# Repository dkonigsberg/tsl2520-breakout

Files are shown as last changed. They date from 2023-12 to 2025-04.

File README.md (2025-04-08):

# TSL2520 Breakout Board

This repository contains the [KiCad](http://kicad.org/) project
with the complete circuit schematics and PCB layout for a breakout
board that supports a certain series of 1.8V light sensors from
[AMS](https://ams-osram.com/).

The supported selection of sensors all appear to be pin-compatible,
interface compatible, and only differ in minor ways. These sensors
include:

* [TSL2520](https://ams-osram.com/en/tsl2520) - Light sensor with Clear and IR channels
* [TSL2521](https://ams-osram.com/en/tsl2521) - Light sensor with Clear and IR channels, and flicker detection
* [TSL2522](https://ams-osram.com/en/tsl2522) - Light sensor with Photopic and IR channels, and flicker detection
* [TCS3410](https://ams-osram.com/en/tcs3410) - Light sensor with Color channels and flicker detection

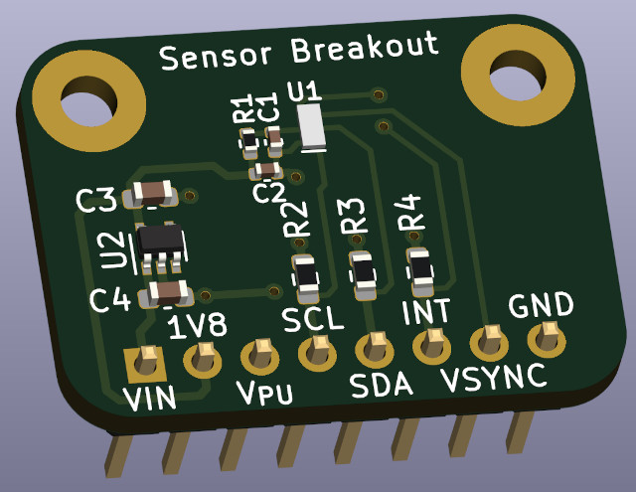
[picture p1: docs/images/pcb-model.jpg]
Board


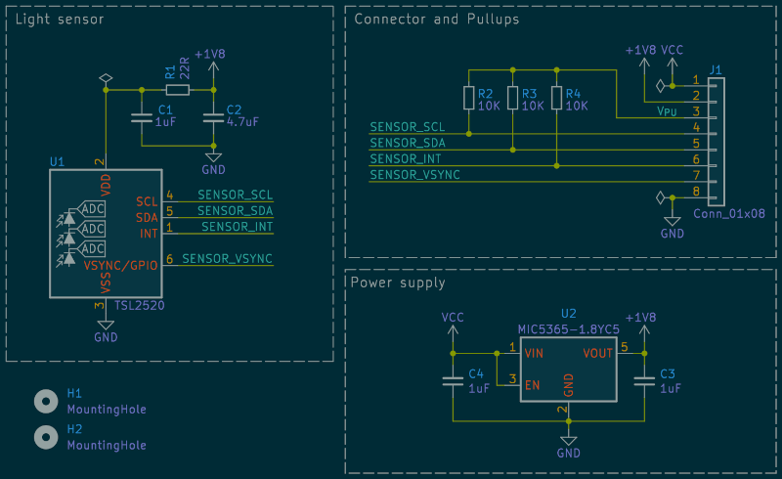
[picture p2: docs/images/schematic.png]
Schematic


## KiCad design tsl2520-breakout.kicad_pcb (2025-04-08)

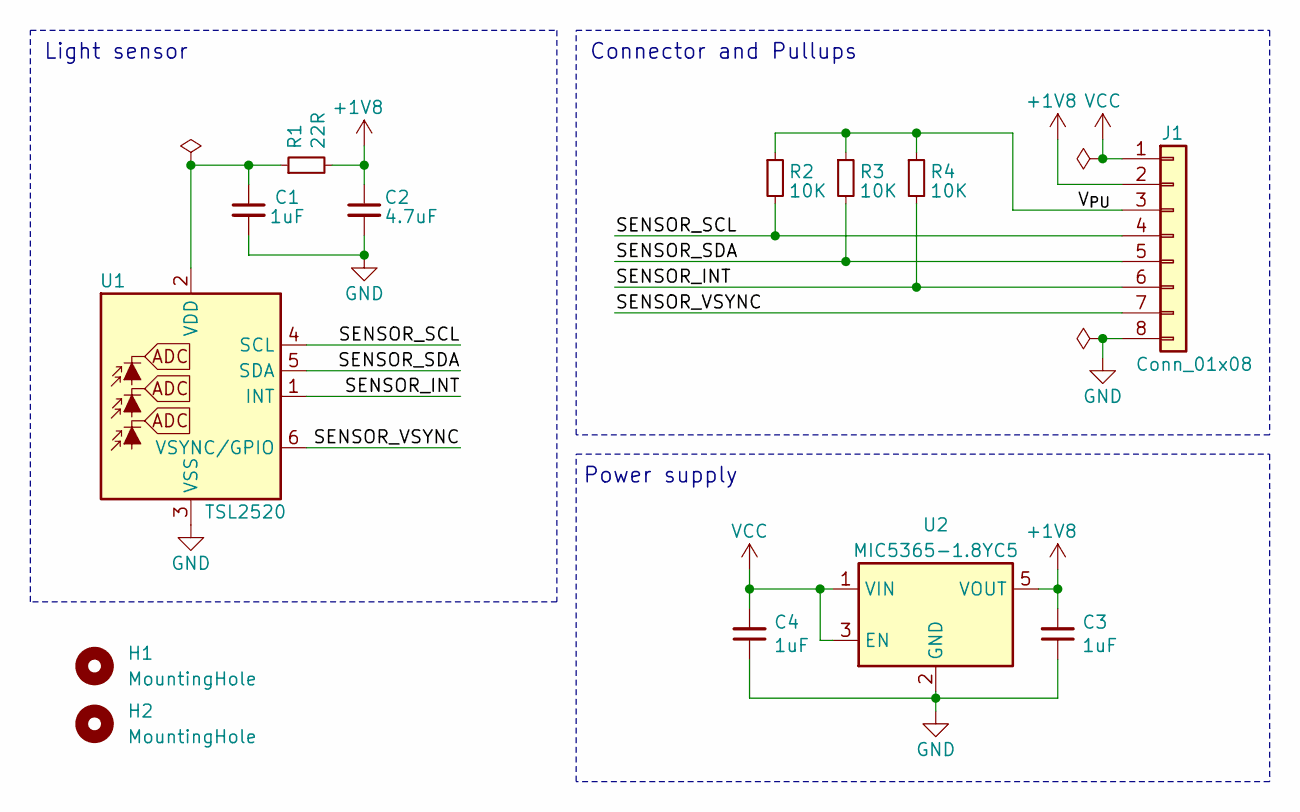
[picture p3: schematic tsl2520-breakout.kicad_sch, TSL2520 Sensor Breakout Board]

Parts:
C1: 1uF; C_0402_1005Metric; Manufacturer PN CL05A105KQ5NNNC
C2: 4.7uF; C_0402_1005Metric; Manufacturer PN CL05A475KQ5NRNC
C3, C4: 1uF; C_0603_1608Metric; Manufacturer PN CL10B105KA8NNNC
H1, H2: MountingHole; MountingHole_2.5mm_Pad
J1: Conn_01x08; PinHeader_1x08_P2.54mm_Vertical
R1: 22R; R_0402_1005Metric; Manufacturer PN AC0402JR-0722RL
R2, R3, R4: 10K; R_0603_1608Metric; Manufacturer PN CRCW060310K0JNEA
U1: TSL2520; AMS_TSL2585_OLGA-6_2x1mm_P0.65mm; Manufacturer PN TSL25203M
U2: MIC5365-1.8YC5; SOT-353_SC-70-5; Manufacturer PN MIC5365-1.8YC5-TR

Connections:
+1V8: C2.1, C3.2, J1.2, R1.2, U2.5 (VOUT)
/SENSOR_INT: J1.6, R4.2, U1.1 (INT)
/SENSOR_SCL: J1.4, R2.2, U1.4 (SCL)
/SENSOR_SDA: J1.5, R3.2, U1.5 (SDA)
/SENSOR_VSYNC: J1.7, U1.6 (VSYNC/GPIO)
/V_{PU}: J1.3, R2.1, R3.1, R4.1
GND: C1.2, C2.2, C3.1, C4.1, J1.8, U1.3 (VSS), U2.2 (GND)
unnamed: C1.1, R1.1, U1.2 (VDD)
VCC: C4.2, J1.1, U2.1 (VIN), U2.3 (EN)

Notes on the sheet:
Light sensor
Connector and Pullups
Power supply

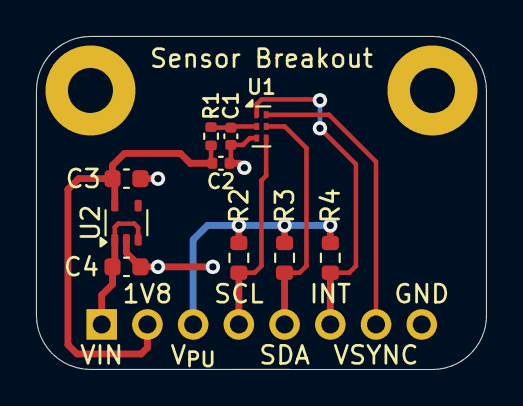
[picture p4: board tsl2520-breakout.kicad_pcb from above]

Board: 2 copper layers, 25.0 x 18.5 mm, 13 parts (1 on the bottom side), 9 nets.

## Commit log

2023-12-05 Rename project files and identifiers
    [tsl2520-breakout.kicad_pcb, tsl2520-breakout.kicad_sch]
2023-12-05 Update symbol, schematic, and PCB layout
    [tsl2520-breakout.kicad_pcb, tsl2520-breakout.kicad_sch]
2025-04-08 Update breakout board design
    Changes for KiCad v9 update and various silkscreen changes
    [tsl2520-breakout.kicad_pcb, tsl2520-breakout.kicad_sch]
